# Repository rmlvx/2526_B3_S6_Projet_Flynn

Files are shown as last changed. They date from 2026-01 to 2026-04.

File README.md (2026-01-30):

# 🤖 Projet_Flynn

<div align="left">

  <p>
    
    
    
    
    <br>
    </p>

  <p>
    <em>Un robot autonome suiveur de ligne avec vision par ordinateur, alliant conception électronique et traitement du signal sur Raspberry Pi.</em>
  </p>

</div>

---

## 📖 À propos

Le **Projet Flynn** a pour objectif de concevoir, prototyper et déployer un robot mobile autonome. Sa mission principale est de suivre des trajectoires (lignes noires ou blanches) sur différents types de surfaces grâce à un système de vision par ordinateur embarqué.

Ce projet s'inscrit dans une démarche d'ingénierie complète, combinant :
* **Conception PCB** sous Kicad.
* **Traitement d'image** et du signal pour la navigation.
* **Pilotage moteur** précis via des drivers silencieux.

<!-- ## 🎥 Démonstration

![Demo](https://via.placeholder.com/800x400?text=Inserer+GIF+ou+Video+du+Robot+Ici) -->

## 🛠️ Architecture Matérielle (BOM)

Le cerveau du robot est une **Raspberry Pi Zero 2W** qui centralise les données des capteurs et assure le pilotage des actionneurs en temps réel.

| Composant | Qté | Fonction | Réf / Doc |
| :--- | :---: | :---: | :---: |
| **Raspberry Pi Zero 2W** | 1 | Unité centrale de contrôle & Vision | [Datasheet](https://www.raspberrypi.com/documentation/computers/raspberry-pi.html#raspberry-pi-zero-2-w) |
| **LSM6DSOX** | 1 | IMU (Accéléromètre/Gyro) - Mesure X,Y,Z | [Datasheet](https://www.st.com/resource/en/datasheet/lsm6dsox.pdf) |
| **TMC2225** | 2 | Driver Moteur (Contrôle précis et silencieux) | [Datasheet](https://www.analog.com/media/en/technical-documentation/data-sheets/TMC2225_datasheet_rev1.14.pdf) |
| **MCP3208** | 1 | ADC 12-bit - Conversion détection couleur | [Datasheet](https://ww1.microchip.com/downloads/en/DeviceDoc/21298E.pdf) |

## 💻 Stack Technique

* **Langage** : 
* **Conception PCB** : 
* **VCS** : 

## 🚀 Installation et Démarrage

### Prérequis

* Une Raspberry Pi Zero 2W avec **Raspberry Pi OS** configuré.
* Accès SSH ou terminal activé.
* Interfaces **SPI** et **I2C** activées via `raspi-config`.

### Installation

Clonez le dépôt sur votre Raspberry Pi et installez les dépendances nécessaires :

```bash
# Cloner le dépôt
git clone [https://github.com/votre-user/projet-flynn.git](https://github.com/votre-user/projet-flynn.git)

# Accéder au dossier
cd projet-flynn

# Installer les dépendances Python
pip install -r requirements.txt
```

## 👥 L'Équipe

<div align="center">

| Raphaël MILVAUX | Emire GUIOSE | Merihene REKIK | Zoléni KOKOLO ZASSI |
| :---: | :---: | :---: | :---: |
| <a href="https://github.com/rmlvx">rmlvx</a> | <a href="https://github.com/emiregse">emiregse</a> | <a href="https://github.com/skelf24">skelf24</a> | <a href="https://github.com/Sikoso774">Sikoso774</a> |

</div>

<br>

<div align="left">
  <strong>©️ 2026 - Raphaël MILVAUX, Emire GUIOSE, Merihene REKIK, Zoléni KOKOLO ZASSI.</strong><br>
  <em>Projet réalisé dans le cadre de la formation ENSEA.</em>
  <br><br>
  Logo ENSEA
</div>

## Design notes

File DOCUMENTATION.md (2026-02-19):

# 📘 Documentation Technique - Projet Flynn

## 1. Présentation du Projet
Ce projet consiste en la réalisation d'un robot auto-équilibré (pendule inversé) piloté par une Raspberry Pi Zero 2W.
Le système repose sur une boucle de contrôle rapide (20Hz+) lisant une centrale inertielle (IMU) et pilotant deux moteurs pas-à-pas.

---

## 2. Architecture Matérielle (Hardware)

### Cœur du système
* **Carte Mère :** Raspberry Pi Zero 2W
* **OS :** Raspberry Pi OS (Legacy/Lite)

### Pinout & Connexions (GPIO BCM)
Voici le mapping validé entre le PCB et le code Python (`config.py`).

| Composant | Signal | Pin Physique (Board) | GPIO (BCM) | Note |
| :--- | :--- | :--- | :--- | :--- |
| **Moteur Gauche** | STEP | 32 | **GPIO 12** | |
| (TMC2225) | DIR | 36 | **GPIO 16** | |
| **Moteur Droit** | STEP | 33 | **GPIO 13** | |
| (TMC2225) | DIR | 31 | **GPIO 6** | |
| **IMU (LSM6DSOX)**| SDA | 3 | **GPIO 2** | Bus I2C-1 |
| | SCL | 5 | **GPIO 3** | Bus I2C-1 |
| **ADC (MCP3208)** | CS | 24 | **GPIO 8** | Bus SPI-0 (CE0) |
| | MOSI | 19 | **GPIO 10** | |
| | MISO | 21 | **GPIO 9** | |
| | SCLK | 23 | **GPIO 11** | |

---

## 3. Architecture Logicielle (Software)

Le code est structuré de manière modulaire pour faciliter la maintenance et les tests.

```text
code/
├── main.py          # Point d'entrée (Lanceur)
├── machine.py       # Cerveau (Logique d'état, Failsafe, Boucle principale)
├── config.py        # Configuration (Constantes, Pinout)
├── logger.py        # Gestionnaire d'enregistrement CSV
└── drivers/         # Couche d'abstraction matérielle (HAL)
    ├── lsm6dsox.py  # Pilote I2C pour Accéléromètre/Gyro
    ├── mcp3208.py   # Pilote SPI pour capteurs analogiques
    └── tmc2225.py   # Pilote GPIO pour moteurs (avec Threading)
```

### Fonctionnalités Clés
1.  **Auto-Réparation (Self-Healing) :** Si l'IMU est déconnecté (faux contact), le système détecte l'erreur, passe en mode "RECONNEXION", et tente de réinitialiser le bus I2C sans planter le script.
2.  **Sécurité (Failsafe) :**
    * Si l'accélération détectée est < 0.1g (chute libre ou erreur lecture 0,0,0) -> **Arrêt Moteurs Immédiat**.
    * Si inclinaison excessive -> **Arrêt Moteurs**.
3.  **Logging :** Chaque session crée un fichier `.csv` dans le dossier `logs/` avec horodatage, données brutes et codes d'état.

---

## 4. Guide d'Installation & Commandes

### Installation initiale
```bash
# 1. Cloner le dépôt
git clone [https://github.com/rmlvx/2526_B3_S6_Projet_Flynn.git](https://github.com/rmlvx/2526_B3_S6_Projet_Flynn.git)
cd 2526_B3_S6_Projet_Flynn/code

# 2. Créer l'environnement virtuel
python -m venv .venv
source .venv/bin/activate

# 3. Installer les dépendances (via uv pour la rapidité)
pip install uv
uv pip install -r requirements.txt
```

### Lancer le robot
```bash
# Toujours activer l'environnement avant
source .venv/bin/activate

# Lancer le programme principal
python main.py
```

---

## 5. Dépannage Git (Mémo)

Si le dépôt local est corrompu ou désynchronisé, voici les commandes de secours utilisées lors du développement.

### Cas 1 : "Je veux juste récupérer la version du serveur (Table Rase)"
*Attention : Ceci efface les modifications locales non sauvegardées.*
```bash
git fetch origin
git reset --hard origin/main
```

### Cas 2 : "Git refuse d'ajouter un dossier (Submodule error)"
Si un dossier (ex: `others/`) contient un `.git` caché :
```bash
# Supprimer le .git intrus
rm -rf others/dossier_problematique/.git
# Retirer du cache git
git rm --cached others/dossier_problematique
# Ajouter proprement
git add .
```

### Cas 3 : "Push rejeté (Updates were rejected)"
Si l'historique local a été recréé (reset) et diffère du serveur :
```bash
git push -u origin main --force
```

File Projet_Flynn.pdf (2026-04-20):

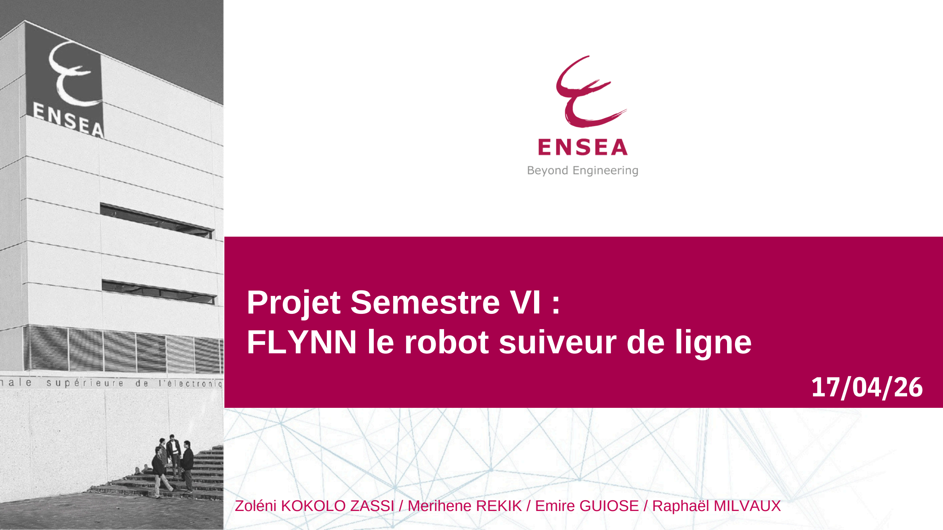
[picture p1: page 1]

# Projet Semestre VI : FLYNN le robot suiveur de ligne

Zoléni KOKOLO ZASSI / Merihene REKIK / Emire GUIOSE / Raphaël MILVAUX

17/04/26

# SOMMAIRE

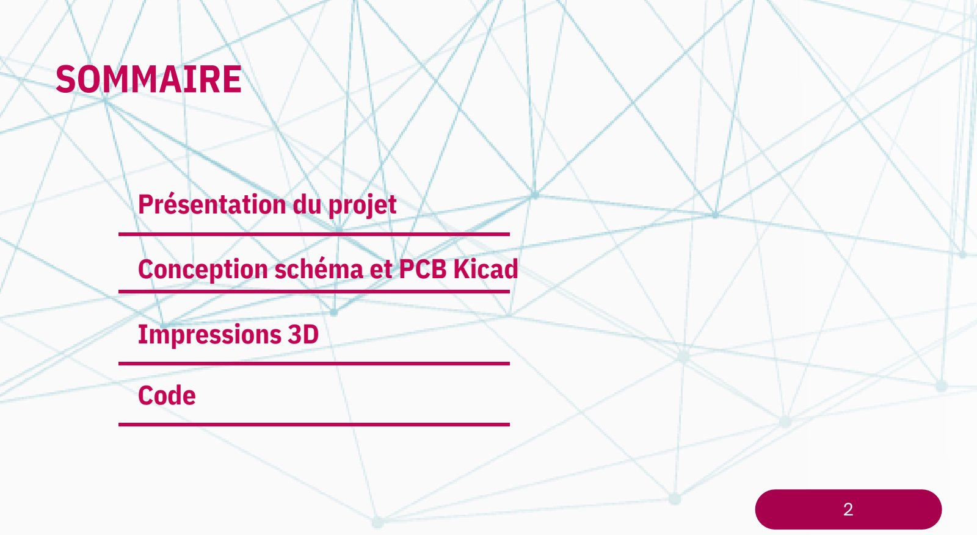
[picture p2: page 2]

# Conception schéma et PCB Kicad

# Impressions 3D

# Code

# Présentation du projet

2

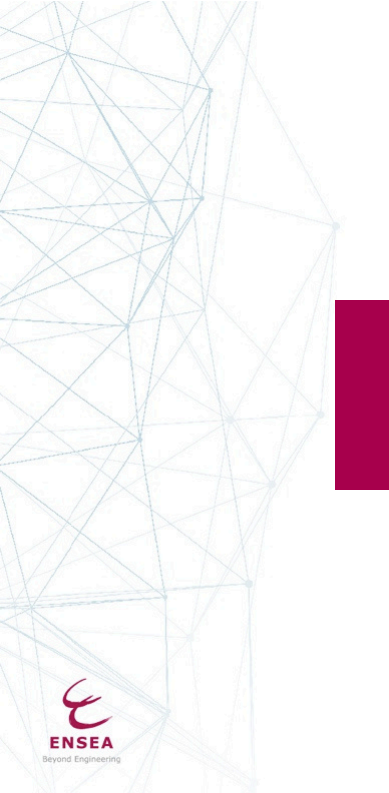
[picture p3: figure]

3

# PRESENTATION DU PROJET

# DEMONSTRATION

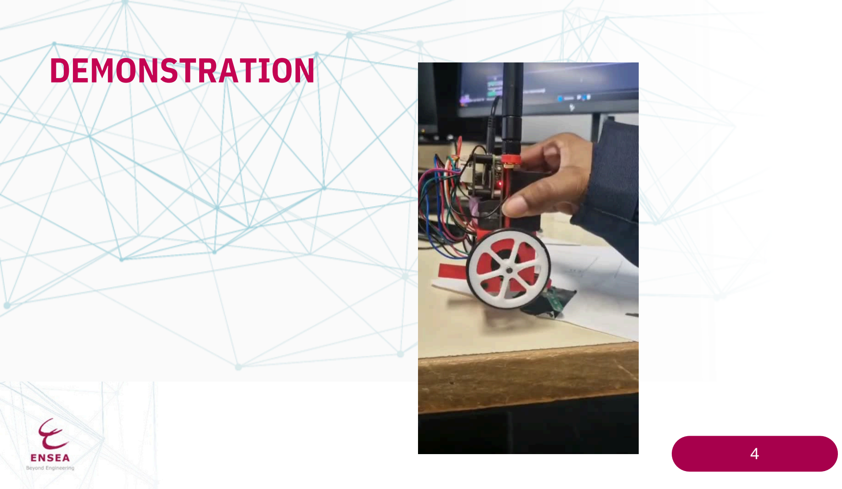
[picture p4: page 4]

4

## MCP3208

## TMC2225

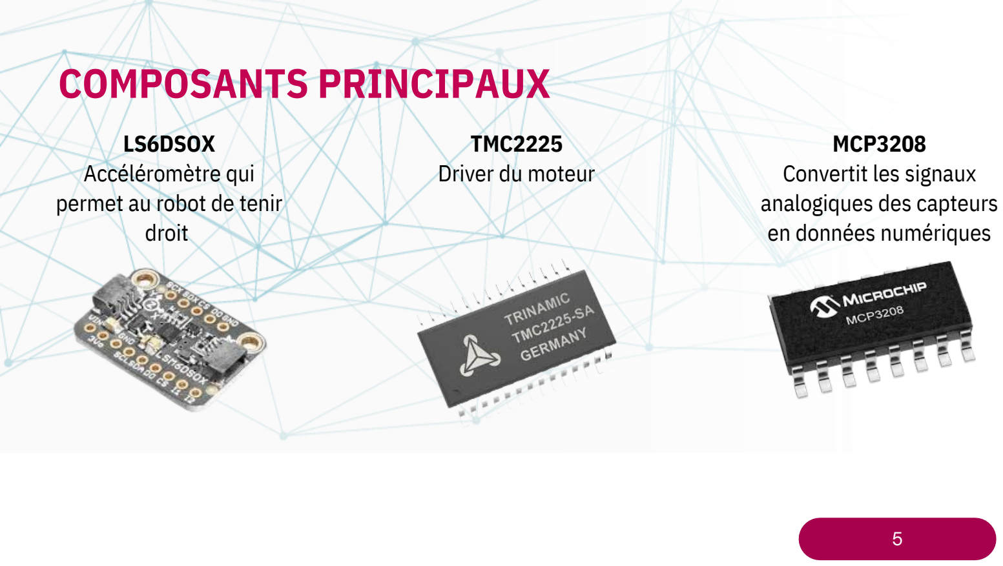
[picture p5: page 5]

5

## Convertit les signaux analogiques des capteurs en données numériques

## Driver du moteur

## LS6DSOX

## Accéléromètre qui permet au robot de tenir droit

# COMPOSANTS PRINCIPAUX

6

# FONCTIONNEMENT DU ROBOT

Le MCP3208 - CAN
exploitables par le
microcontrôleur

Le LSM6DSOX
mesure l’inclinaison
et la rotation du robot

Le microcontrôleur
récupère toutes les
données et calcule
l’erreur par rapport à
la position idéale

Un correcteur (PID)
traite cette erreur
pour déterminer la
commande à
appliquer

Les capteurs
infrarouges
détectent la position
de la ligne

Les TMC2225
reçoivent cette
commande et
pilotent les moteurs

Les moteurs
ajustent la vitesse
des roues pour
corriger la
trajectoire et
maintenir l’équilibre

Les capteurs
mesurent à nouveau
la position ->
répétition en boucle
des étapes

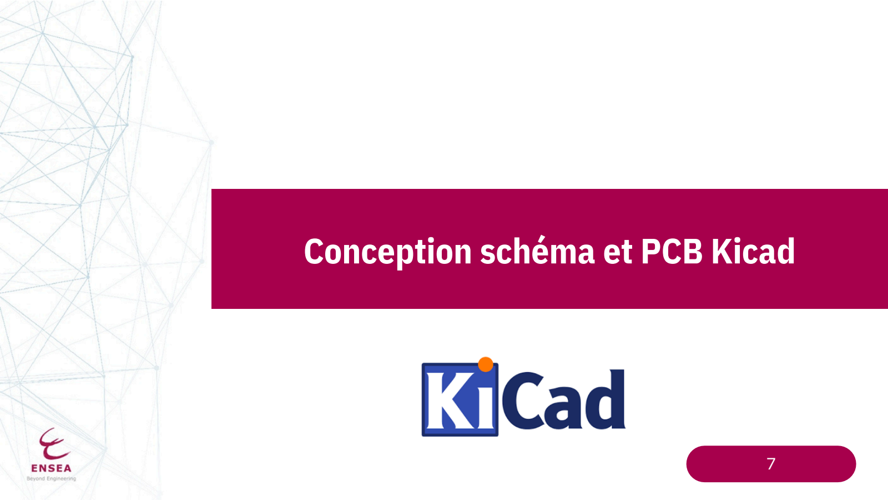
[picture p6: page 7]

# Conception schéma et PCB Kicad

7

# CONCEPTION SCHEMA KICAD

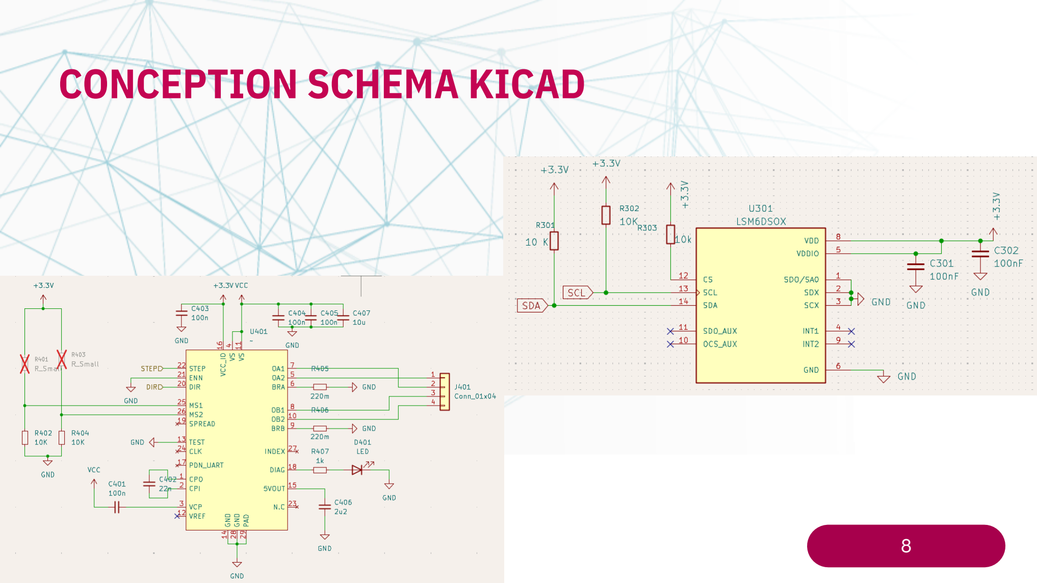
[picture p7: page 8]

8

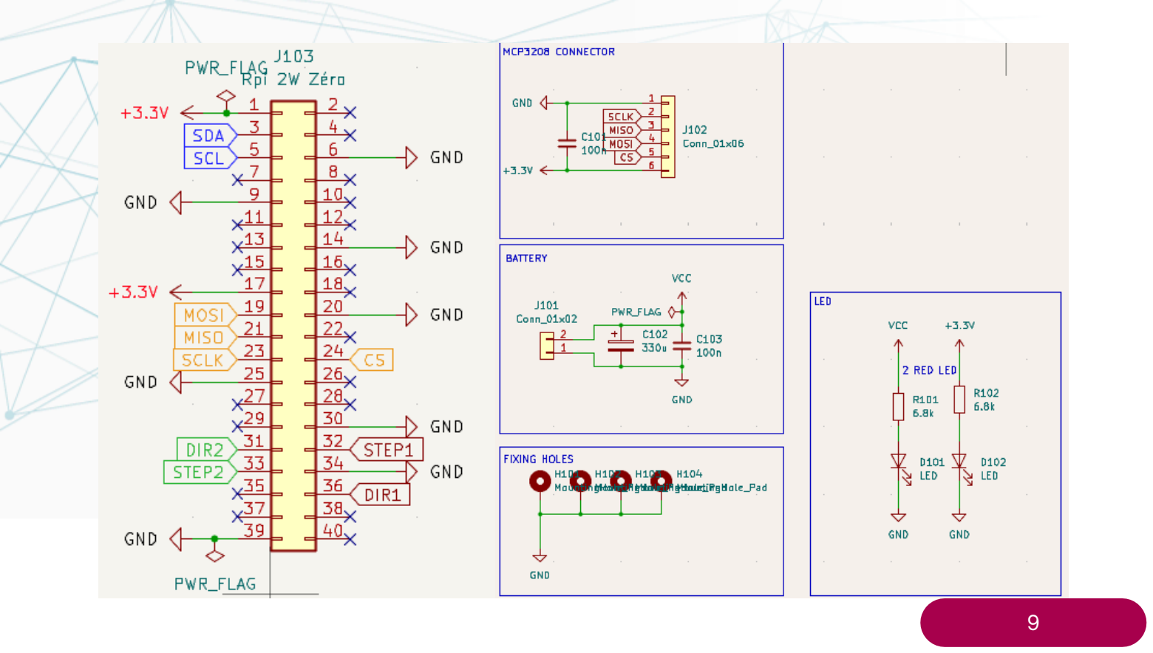
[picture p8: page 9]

9

# CONCEPTION PCB KICAD

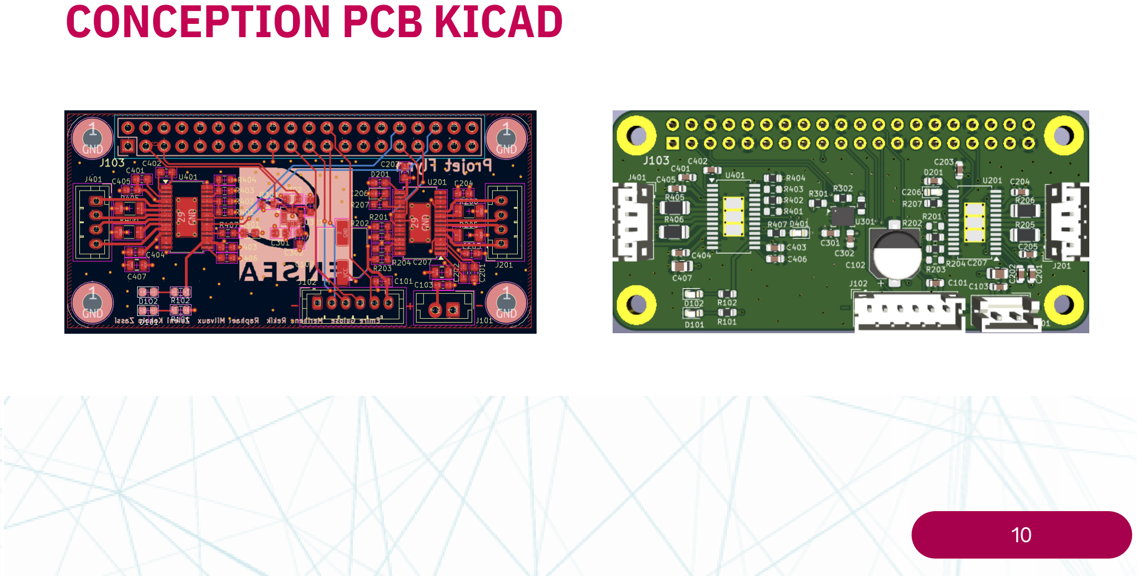
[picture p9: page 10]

10

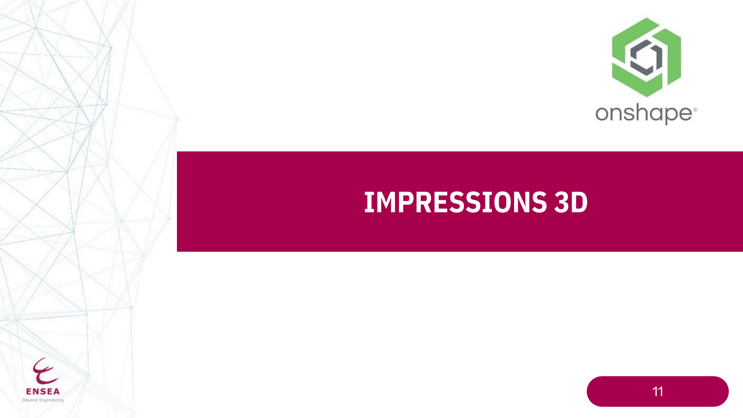
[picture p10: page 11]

11

# IMPRESSIONS 3D

## Partie inférieur:

# STRUCTURE DU ROBOT

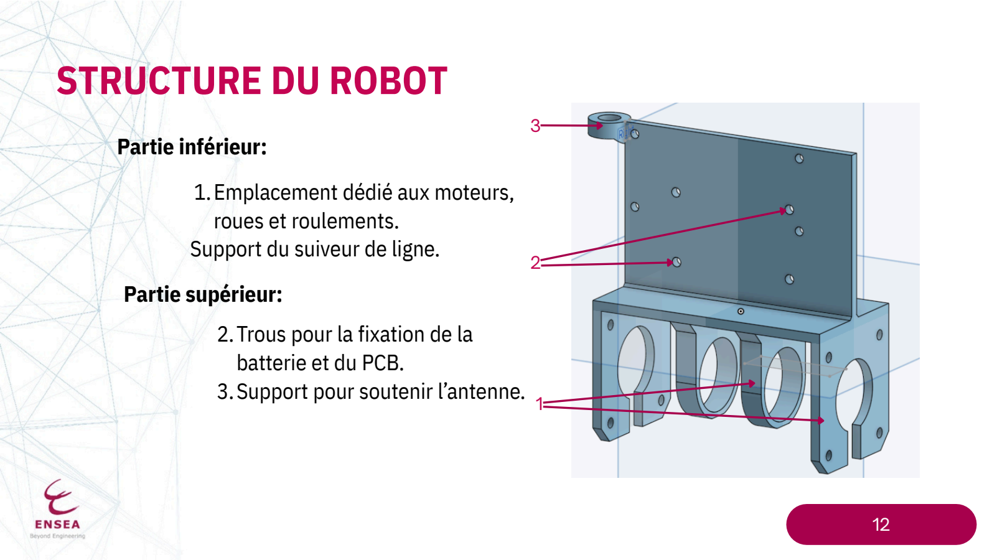
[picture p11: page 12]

12

1.Emplacement dédié aux moteurs, roues et roulements.
Support du suiveur de ligne.

## Partie supérieur:

2

3

1

## 2.Trous pour la fixation de la

batterie et du PCB.
3.Support pour soutenir l’antenne.

# DESIGN DU “T”

## Objectif de la pièce :

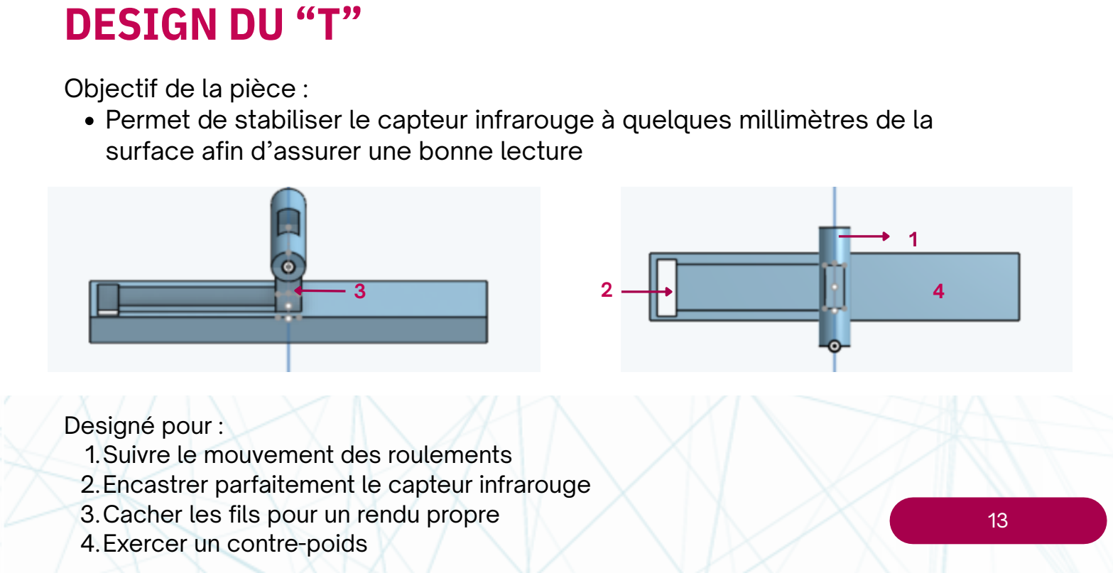
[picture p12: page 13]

## Permet de stabiliser le capteur infrarouge à quelques millimètres de la surface afin d’assurer une bonne lecture

## Designé pour : 1.Suivre le mouvement des roulements 2.Encastrer parfaitement le capteur infrarouge 3.Cacher les fils pour un rendu propre 4.Exercer un contre-poids

13

1

3 | 2 | 4

# ASSEMBLAGE

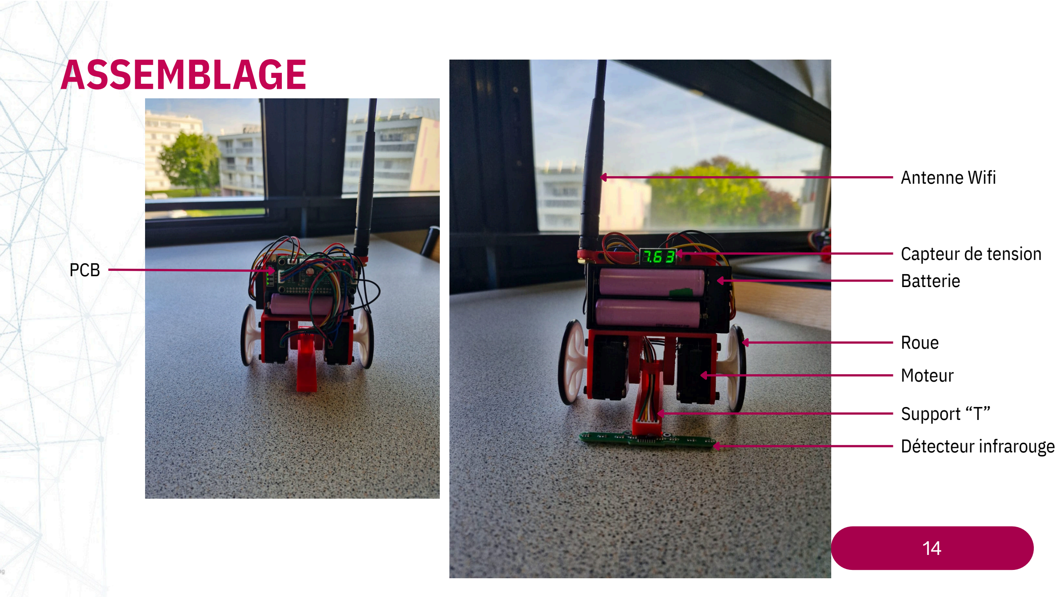
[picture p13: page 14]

14

### Antenne Wifi

### Capteur de tension Batterie

### Roue Moteur

### Support “T” Détecteur infrarouge

### PCB

# CODE

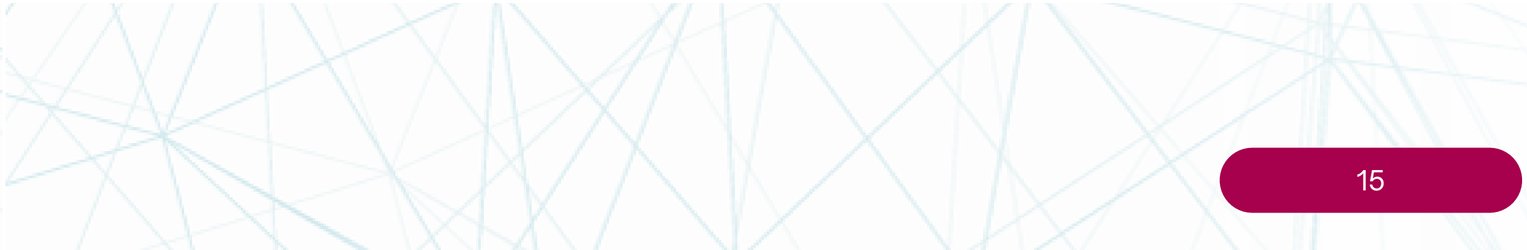
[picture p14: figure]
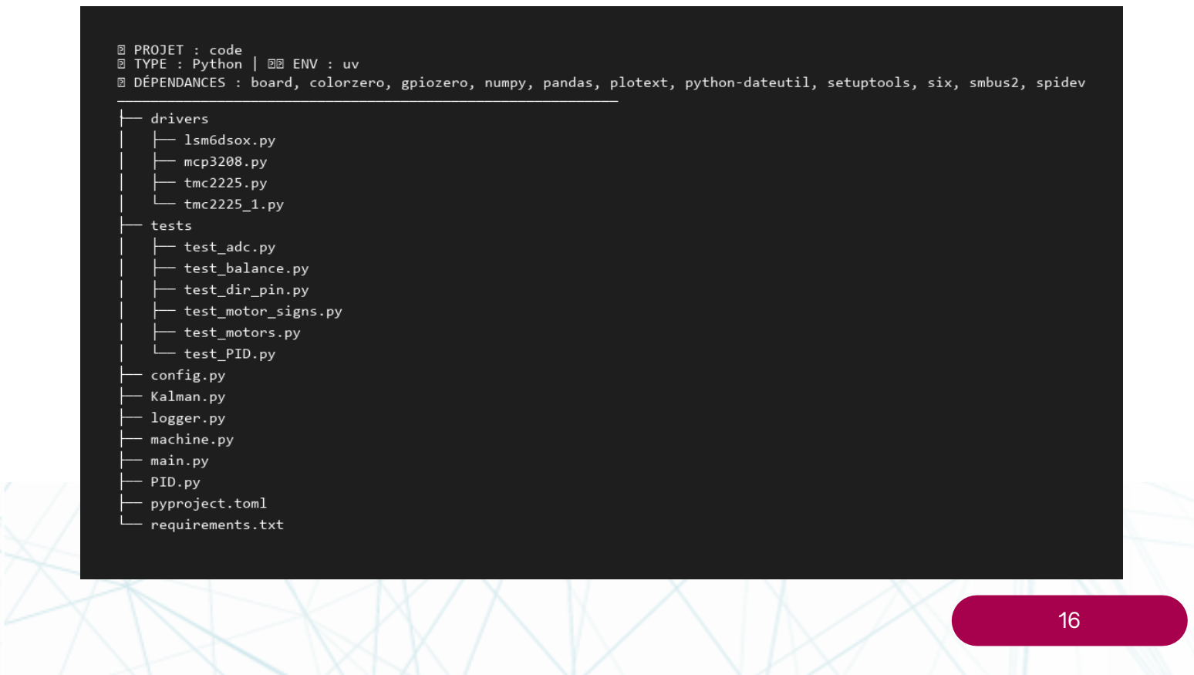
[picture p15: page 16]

16

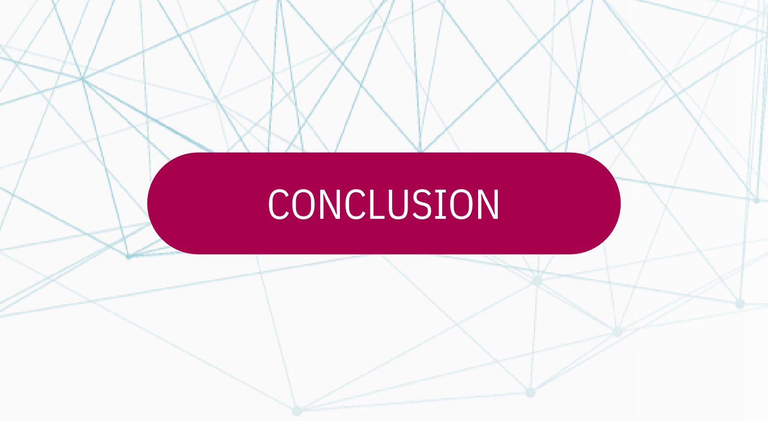
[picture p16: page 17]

# CONCLUSION

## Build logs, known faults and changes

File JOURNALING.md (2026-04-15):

# 🗒️ Journaling

Ce fichier retrace les jours du projet

***

## Jour 1 : 2026-01-20

- Le professeur M. Nicolas PAPAZOGLOU nous a chargé de concevoir un PCB de A à Z qui doit s'adpater sur la Raspberry PI Zero 2W avec ses PINS pour commander un moteur qui dirigera le robot suiveur de lignes FLYNN.
- On a commencé à prendre en main la section "Projects" d'un répertoire GitHub. Raphaël a créer le répertoire du projet et a ouvert cette section pour assigner des ToDo aux mebres du groupe.
- Pour partager et déposer le répértoire sans rien casser du travail des autres membres :
  - a. Faire la commande ``git clone https://github.com/user/nom_du_projet`` pour recopier le projet
  - b. Faire ses modifications puis faire ``git add .`` et ``git commit -m "Nom du message"``
  - c. Lier le projet Git local avec GitHub : ``git remote add origin https://github.com/user/nom_du_projet``
  - d. Si votre brache est nommé master, la renommer avec main avec cette commande : git branch -m master main
  - Rémettre à jour le projet avec git pull et publier le projet git push origin main

***

## Jour 2 : 2026-01-20

- Avancement des schémas des composants sur KICAD
- Finition de la documentation & augmentation du remplissage du journaling

***

## Jour 3 : 2026-01-23

M. Fiack observe nos schémas KICAD pour donner des observations.

- Les labels globaux à éviter, mettre des label hiérarchiques.
- Si on se trompe, on peut modifier les valeurs de ces labels et cela se modifie directement avec le schéma.
- Tracer des lignes de séparation au lieu d'avoir des rectangles.
- Faire un schéma en 2D pour savoir comprendre ce que l'on peut mettre.
- Risque de court-circuit si on lie le ``+3.3V`` du mosfet avec le +``3.3V`` de la Raspberry PI...
- La Rapsberry a besoin d'une tension de ``+5V``.
- Power_Supply (Faire une page en + )
- Brancher les LED pour vérifier que le courant passe bien.
- On met une résistance pour limiter le courant pour éviter de faire cramer la LED.
- Capacités de découplage

A 11h, M. Papazoglou nous a expliqué quelles empreintes il faudrait mettre pour chaque résistance, condensateur, etc.

***

## Jour 4 : 2026-01-26

- 08:45 : M. PAPAZOGLOU a corrigé lquelques erreurs rencontrées lors de la conception du PCB sur PCB Editor sur Kicad sur l'OS Ubuntu.
- 08:52 : Correction des erreurs dans le logiciel Kicad sur Ubuntu.
- 10:02 : Patricia est venue nous aider sur les corrections de la conception du PCB sur les problèmes de routage.
- 11:30 : On continue à développer le  ``README.md`` et finition su schéma 3D du PCB.
- 12h - 14h : [PAUSE]
- 13:41 : M. Fiack est venu nous voir pour vérifier le PCB et voir si il y a des erreurs.
- 15:32 : On refait le diagramme de Gantt de la section "Projects" et mettre les MPN.
- 16:15 : Génération des fichiers de fabrication en Gerber sur Kicad 9.0.
- 16:28 : La roadmap a été refaite.

***

## Jour 5: 2026-01-30

- 10:31 : On essaie de sauvegarder notre code sur GitHub pour pouvoir continuer nos tests.

## Jour 6: 2026-02-17

- Emire et Merihene sont partis souder des composants, Raphaël a aidé à la conception 3D du chassis du robot. Zoléni a repris le code déjà fait sur GitHub pour le reporter à nouveau.

## Jour 7: 2026-02-18

- 08:53 : Emire, Merihene et Raphaël concoivent une pièce 3D sur Onshape pour que le cateur TMC2225 suive le mouvement du robot FLYNN.
- 08:57 : Je suis en train de vérifier que le code fonctionne sur la Raspberry PI et que tous les codes fonctionnent bien.

ToDo :

- [x] Concevoir la pièce.
- [x] Adapter le code par rapport au PCB

Modification et impression des pièces de test.

## Jour 8: 2026-02-19

- Validation du code Python sur l'accéléromètre et cela fonctionne toujours aussi bien. C'est validé !

## Jour 9: 2026-02-20

- Réparation de l'antenne WIFI.
- Test des moteurs : Cela ne fonctionne pas encore.

## Jour 10 : 2026-03-17

- Tentative d'assemblage du code ADC d'origine avec le code. Si le robot détecte selon lui du NOIR, il avance, sinon il s'arrête.

## Jour 11: 2026-04-15

- Faire le Canva

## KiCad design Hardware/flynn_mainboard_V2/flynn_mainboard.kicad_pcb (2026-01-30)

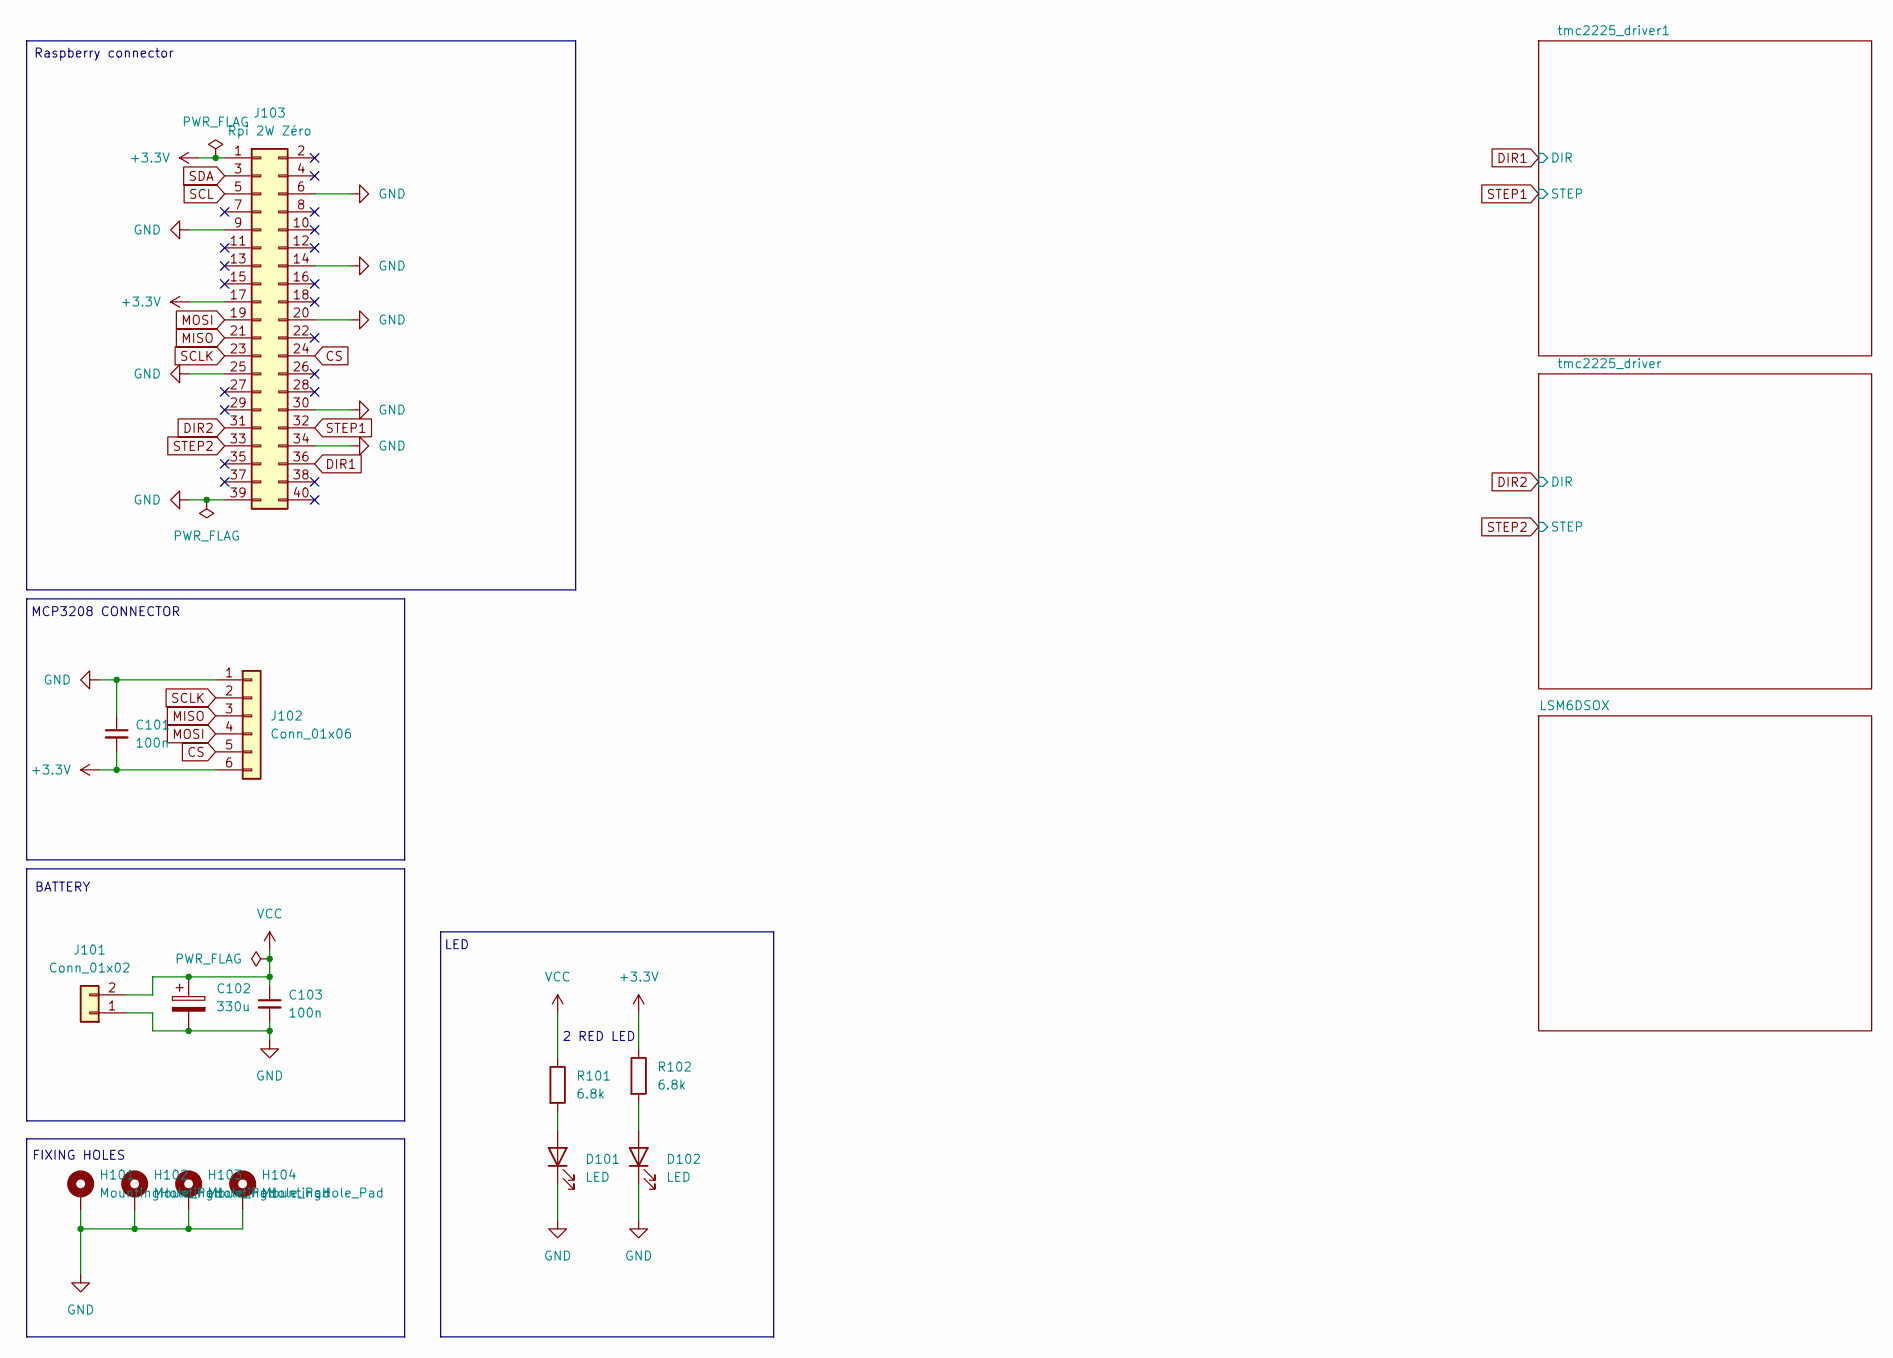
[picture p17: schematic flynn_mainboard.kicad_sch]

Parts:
C101, C103: 100n; C_0603_1608Metric; MPN 885012206071
C102: 330u; CP_Elec_6.3x5.4
D101, D102: LED; LED_0603_1608Metric; MPN 150060GS55040
H101, H102, H103, H104: MountingHole_Pad; MountingHole_2.7mm_M2.5_Pad
J101: Conn_01x02; JST_EH_B2B-EH-A_1x02_P2.50mm_Vertical
J102: Conn_01x06; JST_PH_B6B-PH-K_1x06_P2.00mm_Vertical
J103: Rpi 2W Zéro; PinSocket_2x20_P2.54mm_Vertical
R101, R102: 6.8k; R_0603_1608Metric

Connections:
+3.3V: C101.2, J102.6, J103.1, J103.17, R102.1; also elsewhere on the board
CS: J102.5, J103.24
DIR1: J103.36; also elsewhere on the board
DIR2: J103.31; also elsewhere on the board
GND: C101.1, C102.2, C103.2, D101.1 (K), D102.1 (K), H101.1, H102.1, H103.1, H104.1, J101.1, J102.1, J103.6, J103.9, J103.14, J103.20, J103.25, J103.30, J103.34, J103.39; also elsewhere on the board
MISO: J102.3, J103.21
MOSI: J102.4, J103.19
unnamed: D101.2 (A), R101.2
unnamed: D102.2 (A), R102.2
SCL: J103.5; also elsewhere on the board
SCLK: J102.2, J103.23
SDA: J103.3; also elsewhere on the board
STEP1: J103.32; also elsewhere on the board
STEP2: J103.33; also elsewhere on the board
VCC: C102.1, C103.1, J101.2, R101.1; also elsewhere on the board

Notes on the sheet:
FIXING HOLES
2 RED LED
BATTERY
LED
MCP3208 CONNECTOR
Raspberry connector

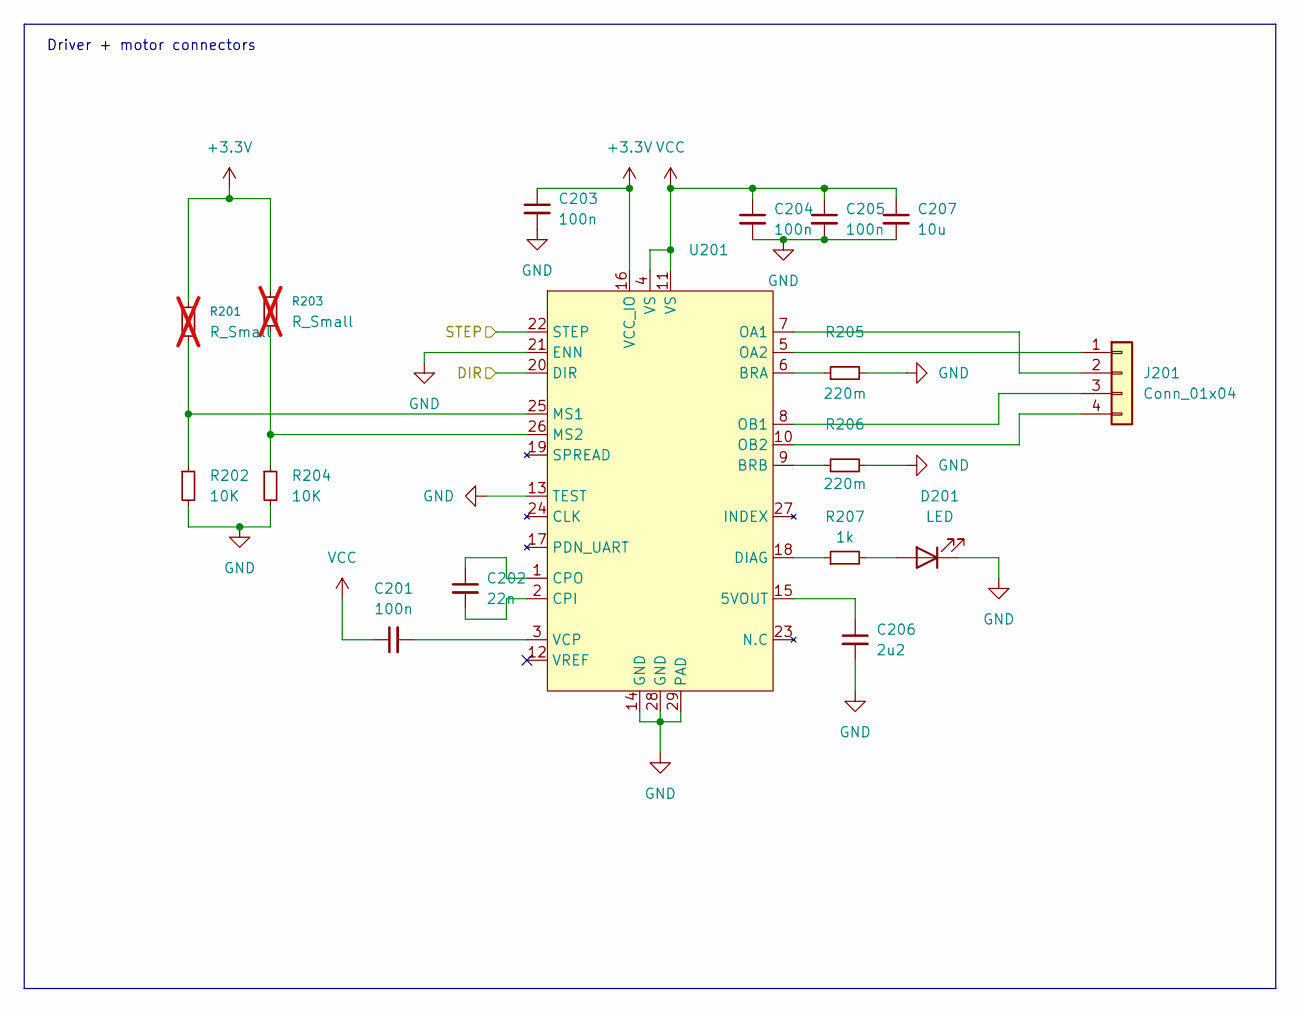
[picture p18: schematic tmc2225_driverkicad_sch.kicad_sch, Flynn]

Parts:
C201, C203, C204, C205: 100n; C_0603_1608Metric; MPN 885012206071
C202: 22n; C_0603_1608Metric; MPN 885012206067
C206: 2u2; C_0603_1608Metric; MPN 885 012 106 018
C207: 10u; C_0805_2012Metric; MPN 885012107014
D201: LED; LED_0603_1608Metric
J201: Conn_01x04; JST_PH_B4B-PH-K_1x04_P2.00mm_Vertical
R201, R203: R_Small; R_0603_1608Metric; not fitted
R202, R204: 10K; R_0603_1608Metric
R205, R206: 220m; R_1206_3216Metric
R207: 1k; R_0603_1608Metric
U201: HTSSOP-28-1EP_4.4x9.7mm_P0.65mm_EP2.85x5.4mm_ThermalVias

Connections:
+3.3V: C203.1, R201.1, R203.1, U201.16 (VCC_IO); also elsewhere on the board
DIR2: U201.20 (DIR); also elsewhere on the board
GND: C203.2, C204.2, C205.2, C206.2, C207.2, D201.1 (K), R202.2, R204.2, R205.2, R206.2, U201.13 (TEST), U201.14 (GND), U201.21 (ENN), U201.28 (GND), U201.29 (PAD); also elsewhere on the board
unnamed: D201.2 (A), R207.2
unnamed: J201.1, U201.5 (OA2)
unnamed: J201.2, U201.7 (OA1)
unnamed: J201.3, U201.8 (OB1)
unnamed: J201.4, U201.10 (OB2)
unnamed: C206.1, U201.15 (5VOUT)
unnamed: R205.1, U201.6 (BRA)
unnamed: R206.1, U201.9 (BRB)
unnamed: C202.2, U201.2 (CPI)
unnamed: C202.1, U201.1 (CPO)
unnamed: R207.1, U201.18 (DIAG)
unnamed: R201.2, R202.1, U201.25 (MS1)
unnamed: R203.2, R204.1, U201.26 (MS2)
unnamed: C201.2, U201.3 (VCP)
STEP2: U201.22 (STEP); also elsewhere on the board
VCC: C201.1, C204.1, C205.1, C207.1, U201.4 (VS), U201.11 (VS); also elsewhere on the board

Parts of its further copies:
C401, C403, C404, C405: 100n; C_0603_1608Metric; MPN 885012206071
C402: 22n; C_0603_1608Metric; MPN 885012206067
C406: 2u2; C_0603_1608Metric; MPN 885 012 106 018
C407: 10u; C_0805_2012Metric; MPN 885012107014
D401: LED; LED_0603_1608Metric
J401: Conn_01x04; JST_PH_B4B-PH-K_1x04_P2.00mm_Vertical
R401, R403: R_Small; R_0603_1608Metric; not fitted
R402, R404: 10K; R_0603_1608Metric
R405, R406: 220m; R_1206_3216Metric
R407: 1k; R_0603_1608Metric
U401: HTSSOP-28-1EP_4.4x9.7mm_P0.65mm_EP2.85x5.4mm_ThermalVias

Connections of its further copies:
+3.3V: C403.1, R401.1, R403.1, U401.16 (VCC_IO); also elsewhere on the board
DIR1: U401.20 (DIR); also elsewhere on the board
GND: C403.2, C404.2, C405.2, C406.2, C407.2, D401.1 (K), R402.2, R404.2, R405.2, R406.2, U401.13 (TEST), U401.14 (GND), U401.21 (ENN), U401.28 (GND), U401.29 (PAD); also elsewhere on the board
unnamed: D401.2 (A), R407.2
unnamed: J401.1, U401.5 (OA2)
unnamed: J401.2, U401.7 (OA1)
unnamed: J401.3, U401.8 (OB1)
unnamed: J401.4, U401.10 (OB2)
unnamed: C406.1, U401.15 (5VOUT)
unnamed: R405.1, U401.6 (BRA)
unnamed: R406.1, U401.9 (BRB)
unnamed: C402.2, U401.2 (CPI)
unnamed: C402.1, U401.1 (CPO)
unnamed: R407.1, U401.18 (DIAG)
unnamed: R401.2, R402.1, U401.25 (MS1)
unnamed: R403.2, R404.1, U401.26 (MS2)
unnamed: C401.2, U401.3 (VCP)
STEP1: U401.22 (STEP); also elsewhere on the board
VCC: C401.1, C404.1, C405.1, C407.1, U401.4 (VS), U401.11 (VS); also elsewhere on the board

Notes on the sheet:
Driver + motor connectors

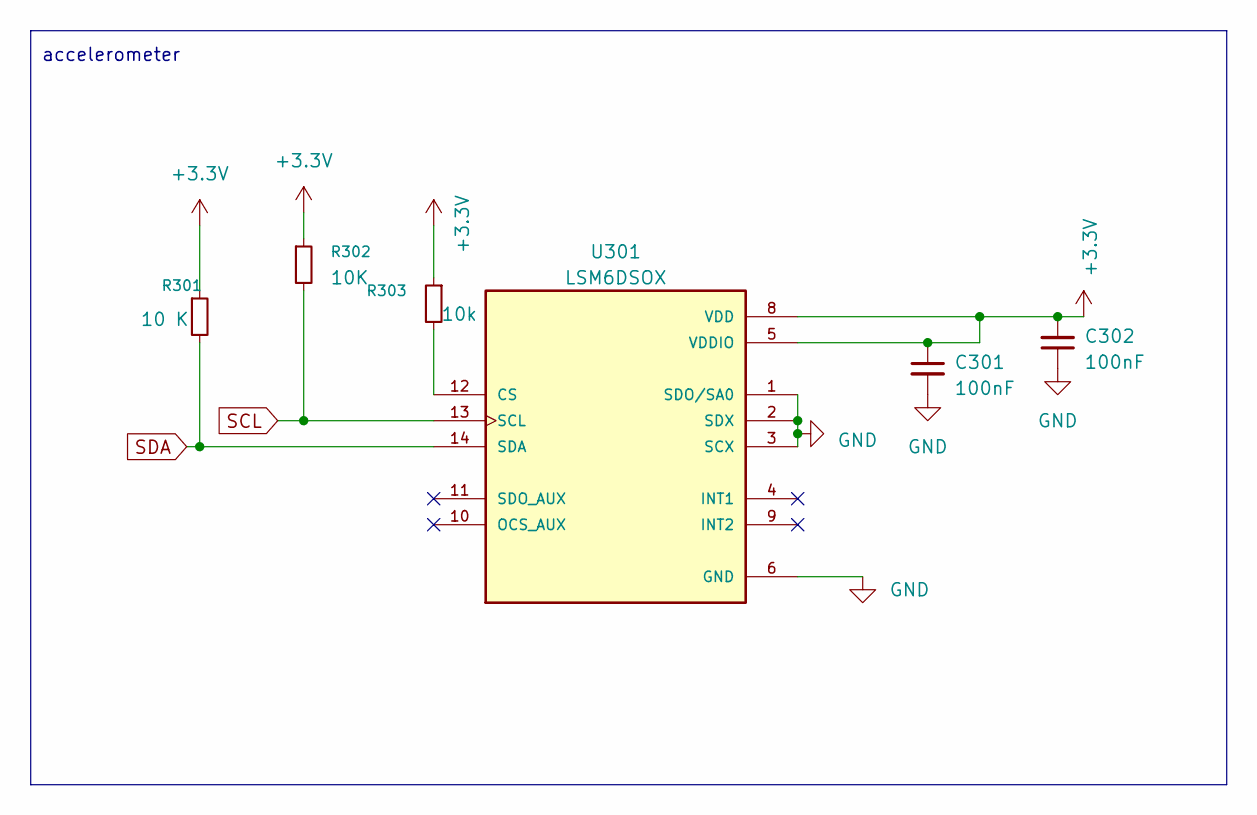
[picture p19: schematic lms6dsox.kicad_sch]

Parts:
C301, C302: 100nF; C_0603_1608Metric; MPN 885012206071
R301: 10 K; R_0603_1608Metric
R302: 10K; R_0603_1608Metric
R303: 10k; R_0603_1608Metric
U301: LSM6DSOX; LGA-14_3x2.5mm_P0.5mm_LayoutBorder3x4y; PARTREV 3.0

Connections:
+3.3V: C301.1, C302.2, R301.1, R302.1, R303.1, U301.5 (VDDIO), U301.8 (VDD); also elsewhere on the board
GND: C301.2, C302.1, U301.1 (SDO/SA0), U301.2 (SDX), U301.3 (SCX), U301.6 (GND), U301.7 (GND); also elsewhere on the board
unnamed: R303.2, U301.12 (CS)
SCL: R302.2, U301.13 (SCL); also elsewhere on the board
SDA: R301.2, U301.14 (SDA); also elsewhere on the board

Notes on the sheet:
accelerometer

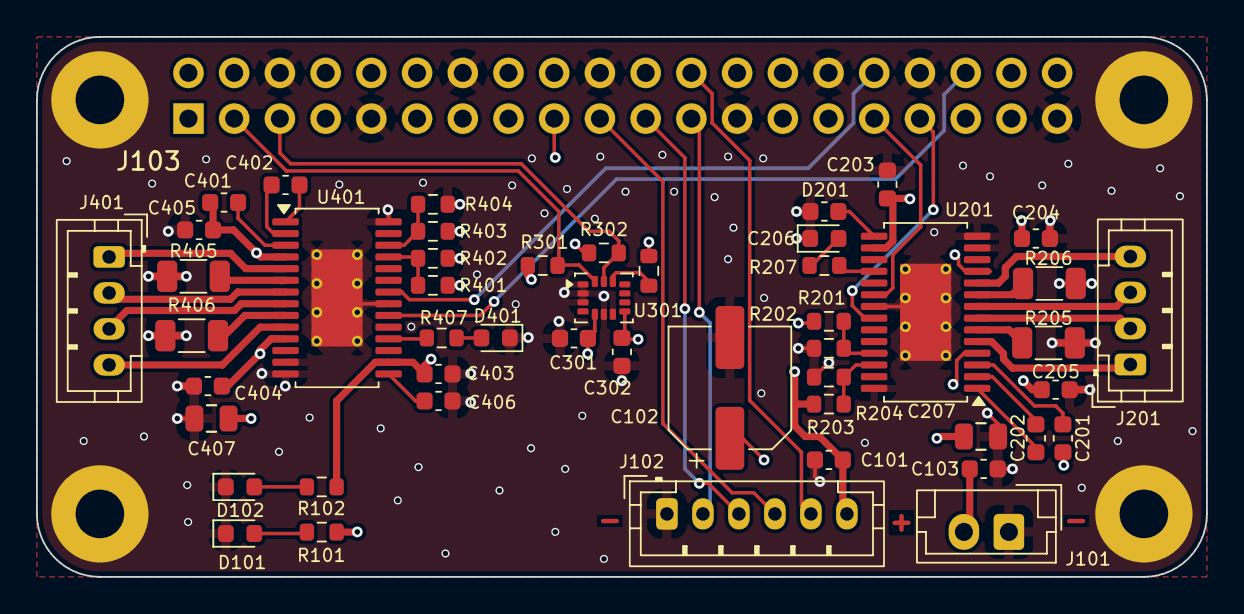
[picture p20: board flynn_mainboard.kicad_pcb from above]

Board: 4 copper layers, 65.0 x 30.0 mm, 54 parts (1 on the bottom side), 44 nets.

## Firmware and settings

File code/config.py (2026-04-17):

from math import pi

# --- SYSTEM ---
# On Raspberry Pi Zero 2W (BCM numbering)
I2C_BUS_ID = 1
SPI_BUS_ID = 0
SPI_DEVICE_ID = 0  # Corresponds to Pin 24 (CE0 / GPIO 8)

# --- CAPTEURS ---
LSM_ADDR = 0x6A    # Default I2C address for the LSM6DSOX
ADC_VREF = 3.3     # Reference voltage (3.3V)

# --- MOTORS (TMC2225) ---
# Physical Pin to BCM GPIO Conversion:
# MOTOR 1 (Left)
# STEP: Pin 32 -> GPIO 12
# DIR:  Pin 36 -> GPIO 16

# MOTOR 2 (Right)
# STEP: Pin 33 -> GPIO 13
# DIR:  Pin 31 -> GPIO 6

# ‘invert’: Set to True if the motor is rotating in the opposite direction from the other one.
# Rule: Tilt the robot forward by hand.
#   → Both wheels move forward          → both invert=False (correct)
#   → One wheel moves forward, the other moves backward  → set invert=True for the one moving backward
#   → Both wheels move backward          → reverse the command sign in test_balance.py

MOTOR_LEFT_PINS = {
    'STEP': 12,
    'DIR': 16,
    'EN': None,
    'invert': True  # ← Set to True if the left motor is spinning backward / The LEFT motor failed the test_motors
}

MOTOR_RIGHT_PINS = {
    'STEP': 13,
    'DIR': 6,
    'EN': None,
    'invert': False   # ← Set to False if the right motor is rotating in the correct direction
}

# --- MECHANICAL SPECIFICATIONS ---
MICROSTEPS = 16
STEPS_PER_REV = 200 * MICROSTEPS
WHEEL_DIAMETER_MM = 65
MM_PER_STEP = (WHEEL_DIAMETER_MM * pi) / STEPS_PER_REV

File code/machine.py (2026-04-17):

import time
import math
import config as cfg
from logger import DataLogger

THRESHOLD = 2007  # Line > 2007 = Black Line,
                  # <= 2007 = White

try:
    from drivers.lsm6dsox import LSM6DSOX
    from drivers.mcp3208 import MCP3208
    from drivers.tmc2225 import TMC2225
except ImportError as e:
    print(f"CRITIQUE : Pilote manquant ({e})")
    exit(1)

class MachineController:
    def __init__(self):
        print("\n--- Initialisation Machine ---")
        
        # 1. Logger
        self.logger = DataLogger()

        # 2. Hardware
        self.imu = None
        self.adc = None
        self.motor_l = None
        self.motor_r = None
        
        self._init_hardware()

    def _init_hardware(self):
        """Initializing physical components"""
        # IMU
        try:
            self.imu = LSM6DSOX(bus_id=cfg.I2C_BUS_ID, address=cfg.LSM_ADDR)
            print("[OK] IMU LSM6DSOX")
        except Exception as e:
            print(f"[ATTENTION] IMU non détecté: {e}")

        # ADC
        try:
            self.adc = MCP3208(bus=cfg.SPI_BUS_ID, device=cfg.SPI_DEVICE_ID, vref=cfg.ADC_VREF)
            self.detector = LineDetector(adc_instance=self.adc, threshold=1.5)
            print("[OK] ADC MCP3208")
            print("Line detector OK")
        except: print("[INFO] Pas d'ADC")

        # Motors
        try:
            self.motor_l = TMC2225(**cfg.MOTOR_LEFT_PINS, name="Gauche")
            self.motor_r = TMC2225(**cfg.MOTOR_RIGHT_PINS, name="Droit")
            print("[OK] Moteurs")
        except: print("[ERREUR] Problème Moteurs")

    def _recover_imu(self):
        """Attempting to reconnect the sensor"""
        if self.imu is None:
            try:
                self.imu = LSM6DSOX(bus_id=cfg.I2C_BUS_ID, address=cfg.LSM_ADDR)
                return True
            except: return False
        else:
            try:
                self.imu.connect()
                return True
            except: return False

    def start(self):
        """Entry point of the main loop"""
        print("\n--- Démarrage Robot (Ctrl+C pour stopper) ---")
        
        # Engine Test (Slow Rotation)
        # if self.motor_l and self.motor_r:
        #     self.motor_l.move_async(5000, 400)
        #     self.motor_r.move_async(-5000, 400)
            
        # Starting the engine threads
        # if self.motor_l: self.motor_l.start()
        # if self.motor_r: self.motor_r.start()
        
        print("--- Démarrage Robot (Ctrl+C pour stopper) ---")

        err_count = 0

        try:
            while True:
                # --- A. Data Acquisition ---
                ax, ay, az = 0.0, 0.0, 0.0
                mag = 0.0
                volts = 0.0
                status = "INIT"
                valid_imu = False

                # 1. IMU Course  + Sanity Check
                try:
                    if self.imu:
                        data = self.imu.read_all()
                        ax, ay, az = data['accel']
                        
                        # Calcul vecteur gravité
                        mag = math.sqrt(ax**2 + ay**2 + az**2)
                        
                        # Si gravité < 0.1g, c'est physiquement impossible -> erreur
                        if mag < 0.1: raise ValueError("Zero-G Error")
                        
                        valid_imu = True
                        err_count = 0
                        status = "OK"
                    else:
                        raise OSError("No Device")

                except (OSError, ValueError, RuntimeError) as e:
                    err_count += 1
                    status = f"ERR: {e}"
                    
                    # Reconnection logic after 2 failed attempts
                    if err_count > 2:
                        status = "RECONNEXION..."
                        if self._recover_imu():
                            err_count = 0

                # 2. ADC Reading
                    if self.adc:
                        # We ask the sensor where the line is
                        tensions_str, position = self.detector.read_status()

                        # Digital signage on the console
                        # print(f"{tensions_str} --> {position}      ", end='\r')
                except: pass

                # --- B. Safety Logic and Line Monitoring ---
                mot_state = "INIT"
                valeurs_brutes = [0] * 8 # Liste vide par défaut pour les 8 capteurs

                if not valid_imu:
                    if self.motor_l: self.motor_l.stop()
                    if self.motor_r: self.motor_r.stop()
                    mot_state = "STOP (SECURITE IMU)"
                
                if self.adc:
                    # 1. Reading from the 8 sensors
                    valeurs_brutes = [self.adc.read_raw(i) for i in range(8)]
                    
                    THRESHOLD = 2007
                    
                    # Reading from the 8 sensors:
                    # active_sensors = range(8) 
                    
                    # (If the robot refuses to stop because the faulty sensors are reading 4000, 
                    # comment out the line above and uncomment the one below
                    capteurs_actifs = [0, 1, 3, 4, 5, 7]
                    
                    # 2. The “any” condition checks whether at least ONE sensor exceeds 2007
                    voit_le_noir = any(valeurs_brutes[i] > THRESHOLD for i in capteurs_actifs)
                    
                    # 3. Action !
                    if voit_le_noir:
                        # At least one sensor detects the line -> Let's move forward!
                        if self.motor_l: self.motor_l.move_async(5000, 400)
                        if self.motor_r: self.motor_r.move_async(5000, 400) # En miroir
                        mot_state = "RUN  (NOIR) "
                    else:
                        # Absolutely NO sensors detect the line -> We stop
                        if self.motor_l: self.motor_l.stop()
                        if self.motor_r: self.motor_r.stop()
                        mot_state = "STOP (BLANC)"

                    # Digital signage for viewing real-time data
                    affichage_vals = " ".join([f"CH{i}:{valeurs_brutes[i]:4d}" for i in capteurs_actifs])
                    print(f"Yeux [{affichage_vals}] | {mot_state}      ", end='\r')

        except KeyboardInterrupt:
            print("\n[USER] Arrêt demandé.")
        finally:
            self.stop()

    def stop(self):
        """Complete shutdown of the entire machine"""
        if self.motor_l: self.motor_l.stop()
        if self.motor_r: self.motor_r.stop()
        if self.adc: self.adc.close()
        self.logger.close()
        print("Machine éteinte.")

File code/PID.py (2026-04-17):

class PIDController:
    """
    PID controller for maintaining equilibrium.

    Key difference from the previous version:
    - dt is passed as an argument to compute() and is not recalculated internally.
      This ensures that the PID and the Kalman filter use exactly
      the same dt, avoiding asymmetric drifts caused by variable delays.
    """

    def __init__(self, kp=0.0, ki=0.0, kd=0.0, target_angle=0.0):
        self.Kp = kp
        self.Ki = ki
        self.Kd = kd

        self.target = target_angle

        self.prev_error = 0.0
        self.integral   = 0.0

        # Anti-windup : upper limit of the integral
        self.max_integral = 1000.0

    def compute(self, current_angle, dt) -> float:
        """
        Calculates the motor control.

        Args:
            current_angle : float — measured angle (degrees)
            dt            : float — cycle duration in seconds (provided by the main loop)

        Returns:
            float — vitesse signée en pas/seconde à envoyer aux moteurs
        """
        if dt <= 0.0:
            dt = 0.001

        # 1. Error
        error = self.target - current_angle

        # 2. Proportional Term
        P = self.Kp * error

        # 3. Full-range term with anti-windup
        self.integral += error * dt
        self.integral  = max(-self.max_integral, min(self.integral, self.max_integral))
        I = self.Ki * self.integral

        # 4. Derived Term
        derivative = (error - self.prev_error) / dt
        D = self.Kd * derivative

        self.prev_error = error

        return P + I + D

    def reset(self):
        """Resets the PID memory (e.g., after a crash)."""
        self.prev_error = 0.0
        self.integral   = 0.0

    def set_tunings(self, kp, ki, kd):
        """Changes the coefficients on the fly."""
        self.Kp = kp
        self.Ki = ki
        self.Kd = kd

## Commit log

2026-01-20 add folders and kicad files
    [flynn_mainboard.kicad_pcb, flynn_mainboard.kicad_sch, lms6dsox.kicad_sch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]
2026-01-21 Ajout du schéma
    [flynn_mainboard.kicad_sch, kicad_tmc_copie.kicad_pcb, kicad_tmc_copie.kicad_sch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]
2026-01-21 suppression fichier
    [kicad_tmc_copie.kicad_pcb, kicad_tmc_copie.kicad_sch]
2026-01-21 nouvelle version
    [Connecteurs.kicad_sch]
2026-01-21 Suppression de fichiers temporaires
2026-01-23 Update README & JOURNALING
    [Connecteurs.kicad_sch, flynn_mainboard.kicad_sch, lms6dsox.kicad_sch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]
2026-01-26 version rooté
    [Connecteurs.kicad_sch, flynn_mainboard.kicad_pcb, flynn_mainboard.kicad_sch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]
2026-01-26 Journaling Update
    [flynn_mainboard.kicad_pcb, flynn_mainboard.kicad_sch, lms6dsox.kicad_sch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]
2026-01-26 Project Update
    [Connecteurs.kicad_sch, flynn_mainboard.kicad_pcb, flynn_mainboard.kicad_sch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]
2026-01-26 Update README 1.5.0
    [flynn_mainboard.kicad_pcb, flynn_mainboard.kicad_sch, lms6dsox.kicad_sch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]
2026-01-26 Projet Flynn complet
    [Connecteurs.kicad_sch, flynn_mainboard.kicad_pcb, flynn_mainboard.kicad_sch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]
2026-01-26 Project_Kicad V1 & V2
    [Connecteurs.kicad_sch, flynn_mainboard.kicad_pcb, flynn_mainboard.kicad_sch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]
2026-01-30 Code added
    [Connecteurs.kicad_sch, flynn_mainboard.kicad_pcb, flynn_mainboard.kicad_sch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]
2026-02-18 Validating Python Code and Journaling Update
    [Connecteurs.kicad_sch, flynn_mainboard.kicad_pcb, flynn_mainboard.kicad_sch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]
2026-02-18 code suitable for PCB
    [session_2026-02-18_10-25-25.csv, session_2026-02-18_10-26-36.csv]
2026-02-19 Journaling Update & Graphic visualization
    [session_2026-02-19_12-55-12.csv, session_2026-02-19_12-56-11.csv, session_2026-02-19_13-14-28.csv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]
2026-02-20 Test des moteurs du robot en cours...
    [session_2026-02-19_12-56-11.csv, session_2026-02-19_13-14-28.csv, session_2026-02-19_13-49-58.csv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]
2026-03-17 Add ADC logic into machine
    [session_2026-03-17_09-53-30.csv]
2026-03-18 Test ADC en cours...
    [session_2026-03-17_09-53-30.csv]
2026-03-20 Aevc 2 capteurs IR défectueux, le moteur roule
    [session_2026-03-18_14-26-52.csv, session_2026-03-18_16-12-39.csv, session_2026-03-20_07-31-51.csv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]
2026-03-20 Test des capteurs...
    [session_2026-03-20_07-31-51.csv, session_2026-03-20_07-33-40.csv, session_2026-03-20_07-51-27.csv]
2026-03-20 Les IR qui fonctionnent dirigent bien les moteurs
2026-03-20 Test du PID...
    [session_2026-03-20_09-54-36.csv]
2026-04-14 Kalman added
    [session_2026-04-14_07-15-16.csv, session_2026-04-14_07-18-41.csv]
2026-04-14 Reparation Attempt
    [session_2026-04-14_07-56-33.csv]
2026-04-15 Tentative de réparation du sens de rotation des moteurs
    [session_2026-04-14_07-18-41.csv, session_2026-04-14_07-56-33.csv]
2026-04-16 Test des roues
    [session_2026-04-15_13-41-55.csv, session_2026-04-16_13-12-20.csv]
2026-04-17 Code documentation completed
    [session_2026-03-18_14-26-52.csv, session_2026-03-18_16-12-39.csv]

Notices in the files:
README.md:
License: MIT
